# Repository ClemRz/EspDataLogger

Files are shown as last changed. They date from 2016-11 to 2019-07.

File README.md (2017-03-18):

# EspDataLogger
Low power data logger using ESP8266.

This is a portable/autonomous data logger that monitors temperature and relative humidity.

## TOC

  - [Precision](#precision)
  - [Power consumption](#power-consumption)
  - [Data storage](#data-storage)
  - [Size and weight](#size-and-weight)
  - [Pictures](#pictures)
  - [Hardware design](#hardware-design)
  - [Software design](#software-design)
  - [User Manual](#user-manual)
  - [User Interface](#user-interface)

## Precision

  - Temperature: ±0.4 °C (max), –10 to 85 °C
  - Relative Humidity: ± 3% RH (max), 0–80% RH

## Power consumption

| Parts \ Power | Running (µA)  | Deep sleep (µA)  |
| --- |:---:| ---:|
| ESP8266 | 900 | 10 |
| SI7021 | 120 | 0.06 |
| LT1529 | 50 | 50 |
| **TOTAL** | **1070** | **60.06** |

Computation of power consumption for a sampling rate of 15 minutes (We estimate that the running time is approximately one seconds):
    
    1070 * 10^-3 * 1/3600 + 60.06 * 10^-3 * 15/60 ≈ 0.015mAh

Considering a battery of 1900mAh this device **could ideally store 126666 points** of data. The main restriction will be the size of the flash memory.

## Data storage

The [FS library](http://esp8266.github.io/Arduino/versions/2.0.0/doc/filesystem.html) is used to store the data in the ESP8266 internal flash memory.

If we consider the smallest flash memory available, which is 64 kilobytes, we can compute the maximum number of data points that can be stored.
The file contains a header composed of the timestamp, tipically 19 chars, 19 chars for wording, the wakeup rate, tipically 3 digits and the version number, 3 digits.
Each point is composed of 3 ints: milliseconds tipically 3 digits, temperature tipically 4 digits, and humidity tipically 2 digits plus 2 coma separators and a EOL char.

    (64000 - (19 + 19 + 3 + 3)) / (3 + 4 + 2 + 2 + 1) = 5329 points of data

Considering a sampling rate of 15 minutes it **could ideally run for more than 55 days** .

## Size and weight

  * Weight: 88g [TBR]
  * Size: 90x70x28mm

## Pictures

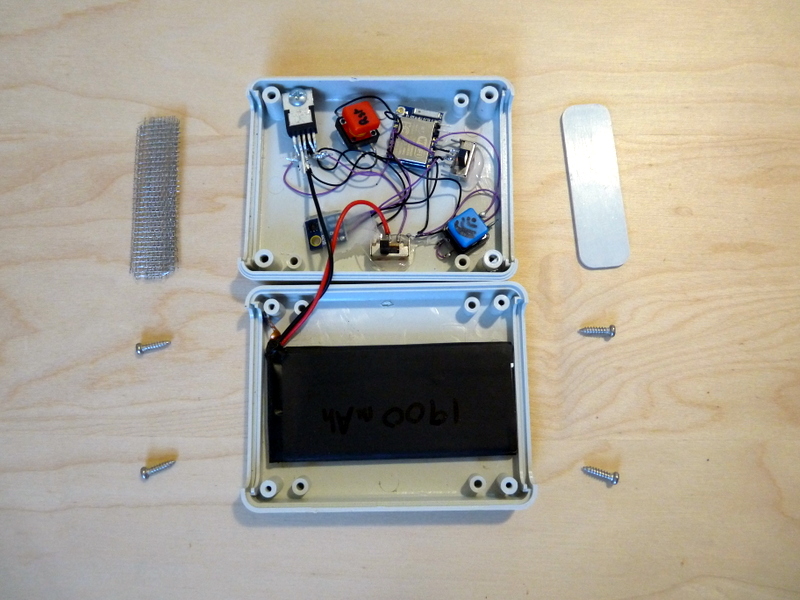
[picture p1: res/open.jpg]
Open


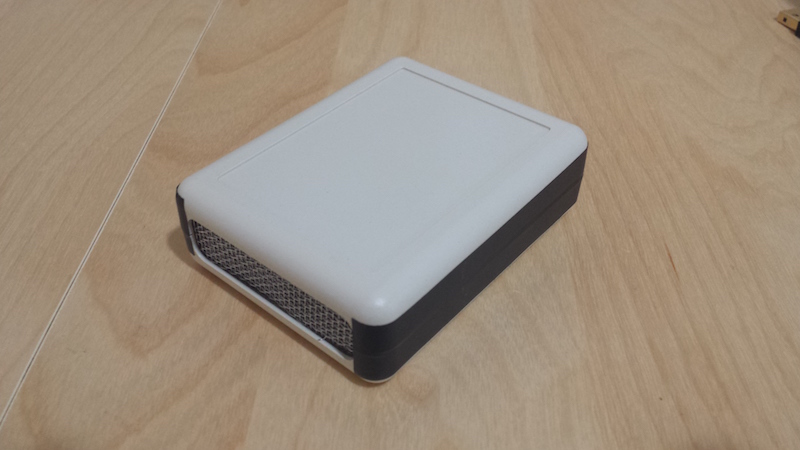
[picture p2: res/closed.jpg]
Closed


## Hardware design

Parts list:

  - ESP8266 Esp07 microcontroler
  - SI7021 temperature and humidity sensor
  - LT1529-3.3 voltage regulator
  - 22uF 100V elec. capacitor
  - 1900mAh 3.7V LiPo battery
  - TP4056 Li-ion charger module
  - 2 switches and 2 push buttons

Remember to remove any LED that would unnecessarily draw current.

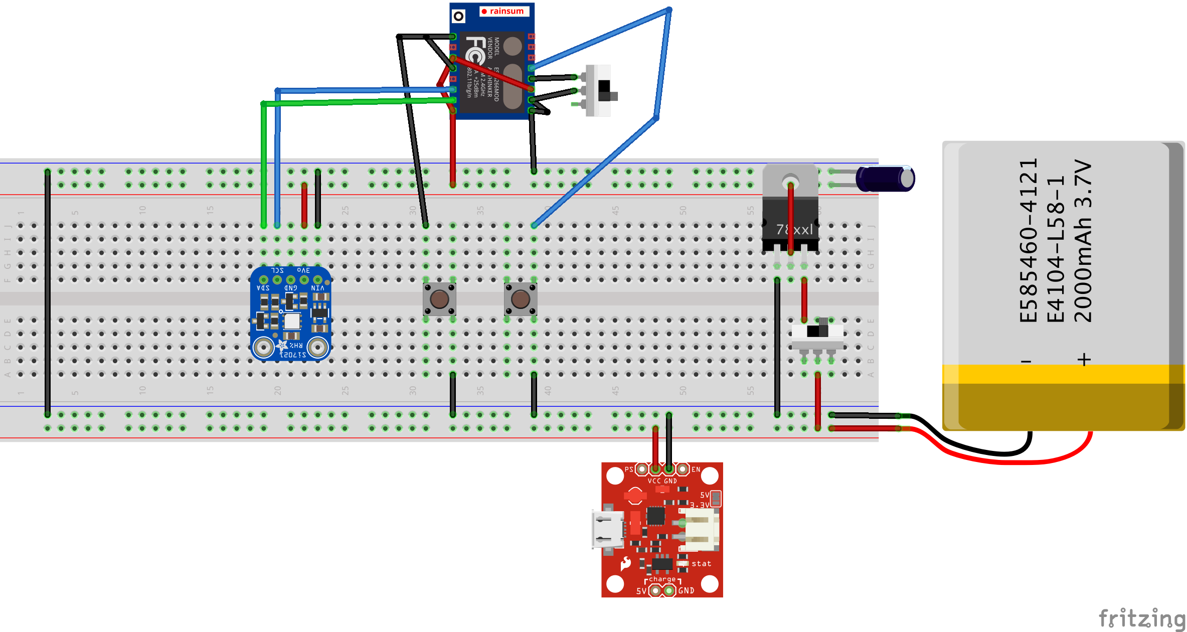
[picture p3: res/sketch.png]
Sketch


## Software design

### Dependencies

  - [SI7021.h library](https://github.com/LowPowerLab/SI7021)

### Parameters

Change the constants according to your needs:

  - DEFAULT_WAKEUP_RATE: This is the default value for how long should the device be sleeping between each data point. In the case the config cannot be read for some reason.

The following are deprecated, you should use the UI in AP mode instead:

  - DEBUG: turn to 1 to get log messages via serial monitor.
  - RETRIEVE: turn to 1 to read the list of data points, stored in the flash memory, via serial monitor.
  - DELETE: turn to 1 to erase the data points from the flash memory.

## User Manual

To turn the AP mode on do the following:

  1. Make sure the circuit is energized.
  2. Push and maintain pushed the button connected to digital pin 4, we'll call it the Wifi button.
  3. Push and release the reset button.
  4. Wait for 3 seconds and release the Wifi button.

To visit the UI do the following:

  1. Connect your device (laptop, tablet, smartphone etc.) to the open Wifi signal named `espDataLogger`.
  2. Open a browser and go to the url [http://192.168.4.1](http://192.168.4.1)

To leave the AP mode and go back to logging mode do either one of the following:

  - In the UI, select `Reset the ESP`.

OR

  - Push and release the reset button.

## User Interface

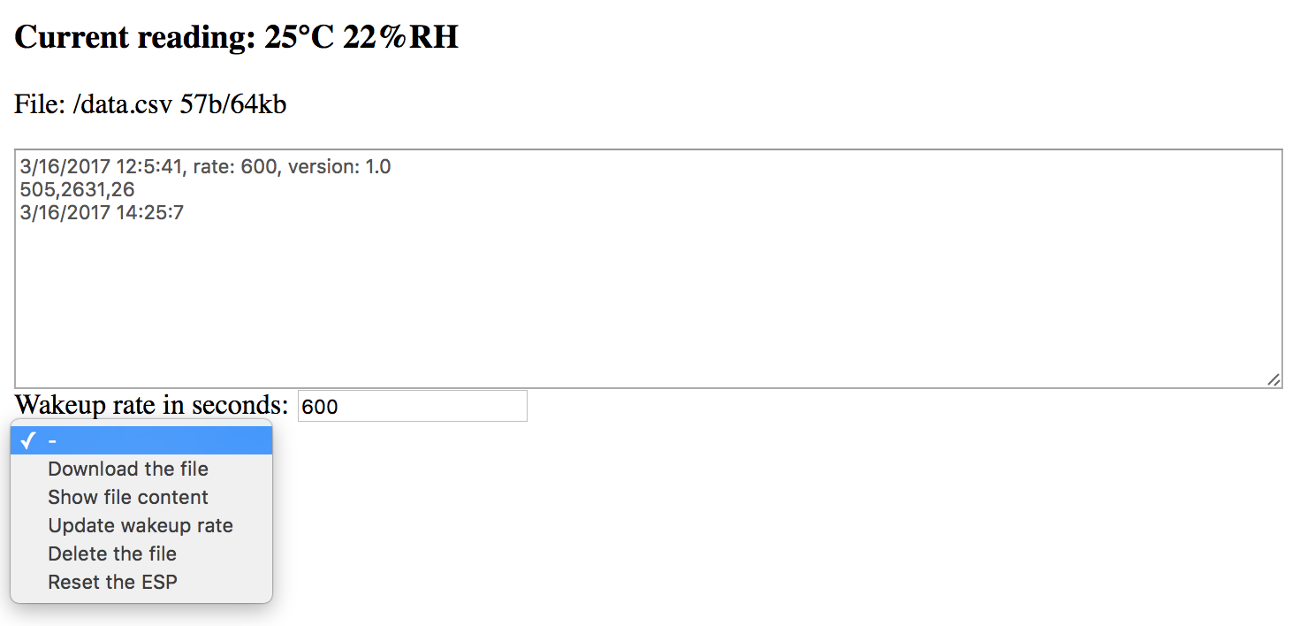
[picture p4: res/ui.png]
UI


The list of actions is quite explicit about what you can do.
When you download the file, the current date and time is appended so you can compute the real interval between each line of data.
Also, when you update the wakeup rate, a new header line is appended to the file to keep track of the change.

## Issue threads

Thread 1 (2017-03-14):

Adds more hardware features

ClemRz, 2017-03-14:
Add the following hardware features:

- log / erase / output **selector**
- reset **push button**
- li-ion **charge controller**

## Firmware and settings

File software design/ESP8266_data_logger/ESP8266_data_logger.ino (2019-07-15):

/*
    Copyright (C) 2016 Clément Ronzon

    This file is part of EspDataLogger.

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
    You should have received a copy of the GNU General Public License
    along with EspDataLogger.  If not, see <http://www.gnu.org/licenses/>.
 */

#include <ESP8266WiFi.h>
#include <WiFiClient.h> 
#include <ESP8266WebServer.h>
#include <Wire.h>
#include <SI7021.h>
#include "FS.h"

#define MICROSEC              1000000L
#define MILLISEC              1000L
#define SEC                   1L
#define MINUTE                (unsigned int) 60L*SEC
#define HOUR                  (unsigned int) 60L*MINUTE
#define DAY                   (unsigned long) 24L*HOUR

#define AP                    4
#define SCL                   12
#define SDA                   13

#define DEFAULT_WAKEUP_RATE   10*MINUTE
#define CONFIG_FILE_PATH      "/cfg.json"
#define DATA_FILE_PATH        "/data.csv"

#define DEBUG                 0        
#define RETRIEVE              0
#define DELETE                0

#define VERSION               "1.1"

const char *ssid = "espDataLogger";
const char compile_date[] = __DATE__ " " __TIME__;

ESP8266WebServer server(80);

SI7021 _sensor;

bool _apMode = false,
     _sensorExists = false;
     
int _celsiusHundredths,
    _humidityPercent,
    _wakeupRate;

String _dateTime;

void setup() {
  initPin();
#if DEBUG || RETRIEVE || DELETE
  initSerial();
#endif  // DEBUG || RETRIEVE || DELETE
  initSI7021();
  initFS();
  setWakeupRate();
  if (_apMode) {
    startAP();
  } else {
    WiFi.mode(WIFI_OFF);
    loggData(); 
  }
}

void loop() {
  if (_apMode) server.handleClient();
}

void startAP(void) {
  initWifiAP();
  initServer();
#if DEBUG
  Serial.println(F("In AP Mode"));
#endif  // DEBUG
}

void loggData(void) {
#if RETRIEVE
  delay(5 * SEC);
  retrieveDataToSerial();
#endif //RETRIEVE
#if DELETE
  delay(5 * SEC);
  _dateTime = compile_date;
  deleteData();
#endif //DELETE
#if !RETRIEVE && !DELETE
  readSensor();
  saveData();
  sleep();
#endif  // !RETRIEVE && !DELETE
#if RETRIEVE || DELETE
  quickSleep();
#endif  // RETRIEVE || DELETE
}

void sleep(void) {
#if DEBUG
  Serial.print(F("Go to sleep for "));
  Serial.print(_wakeupRate * MICROSEC);
  Serial.println(F("us."));
#endif  //DEBUG
  ESP.deepSleep(_wakeupRate * MICROSEC);
}

void quickSleep(void) {
  Serial.print(F("Go to sleep for "));
  Serial.print(1 * MICROSEC);
  Serial.println(F("us."));
  ESP.deepSleep(1 * MICROSEC);
}

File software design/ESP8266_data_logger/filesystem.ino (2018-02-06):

/*
    Copyright (C) 2016 Clément Ronzon

    This file is part of EspDataLogger.

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
    You should have received a copy of the GNU General Public License
    along with EspDataLogger.  If not, see <http://www.gnu.org/licenses/>.
 */

void saveData(void) {
  File file = SPIFFS.open(DATA_FILE_PATH, "a");
  if (file) {
    file.print(millis()); file.print(F(",")); file.print(_celsiusHundredths); file.print(F(",")); file.println(_humidityPercent);
    file.close();
#if DEBUG
  } else {
    Serial.println(F("file open failed"));
#endif  //DEBUG
  }
}

void saveHeaders(void) {
  File file = SPIFFS.open(DATA_FILE_PATH, "a");
  if (file) {
    file.print(_dateTime); file.print(F(", rate: ")); file.print(_wakeupRate); file.print(F(", version: ")); file.println(VERSION);
    file.close();
#if DEBUG
  } else {
    Serial.println(F("file open failed"));
#endif  //DEBUG
  }
}

String getDataAttributes(void) {
  File file = SPIFFS.open(DATA_FILE_PATH, "r");
  String out = "";
  if (file) out.concat(F("File: ")); out.concat(file.name()); out.concat(F(" ")); out.concat(file.size()); out.concat(F("b/64kb"));
  return out;
}

void retrieveDataToSerial(void) {
  File file = SPIFFS.open(DATA_FILE_PATH, "r");
  if (!file) {
    Serial.println(F("file open failed"));
    return;
  }
  Serial.println(F("-- bof --"));
  while(file.available()) {
    Serial.println(file.readStringUntil('\n'));
  }
  Serial.println(F("-- eof --"));
}

String retrieveRawData(void) {
  File file = SPIFFS.open(DATA_FILE_PATH, "r");
  String out = "";
  if (!file) {
    out.concat(F("no data"));
  } else {
    while(file.available()) {
      out.concat(file.readStringUntil('\n')); out.concat(F("\n"));
    }
  }
  out.concat(_dateTime); out.concat(F("\n"));
  return out;
}

void deleteData(void) {
  if (SPIFFS.remove(DATA_FILE_PATH)) {
#if DEBUG
    Serial.print(DATA_FILE_PATH); Serial.println(F(" deleted"));
#endif  //DEBUG
    saveHeaders();
#if DEBUG
  } else {
    Serial.println(F("file delete failed"));
#endif  //DEBUG
  }
}

void setWakeupRate(void) {
  int rate = DEFAULT_WAKEUP_RATE;
  File file = SPIFFS.open(CONFIG_FILE_PATH, "r");
  if (file) {
    while(file.available()) {
      rate = file.readStringUntil('\n').toInt();
    }
    file.close();
#if DEBUG
  } else {
    Serial.println(F("file open failed"));
#endif  //DEBUG
  }
  _wakeupRate = rate;
}

void saveWakeupRate(void) {
  File file = SPIFFS.open(CONFIG_FILE_PATH, "w");
  if (file) {
    file.println(_wakeupRate);
    file.close();
    saveHeaders();
#if DEBUG
  } else {
    Serial.println(F("file open failed"));
#endif  //DEBUG
  }
}

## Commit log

2016-11-19 Fixes programming mode switch
    [sketch.fzz]
2017-03-07 Adds compilation timestamp and millis to the logging file.
2017-03-16 Adds possibility to turn on AP pressing a push button during setup. Adds a UI to be able to download data and configure the wakeup rate. Adds a reset button to the electronic sketch and a li-ion char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
    [sketch.fzz]
2017-03-16 Updates electronic sketch
    [sketch.fzz]
2018-02-06 Enhaces UI for mobile devices

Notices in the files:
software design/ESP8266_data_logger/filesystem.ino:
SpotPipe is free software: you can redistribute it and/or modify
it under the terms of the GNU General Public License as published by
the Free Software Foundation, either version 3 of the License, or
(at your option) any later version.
